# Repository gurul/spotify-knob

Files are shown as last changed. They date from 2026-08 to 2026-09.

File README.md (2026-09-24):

<p align="center">
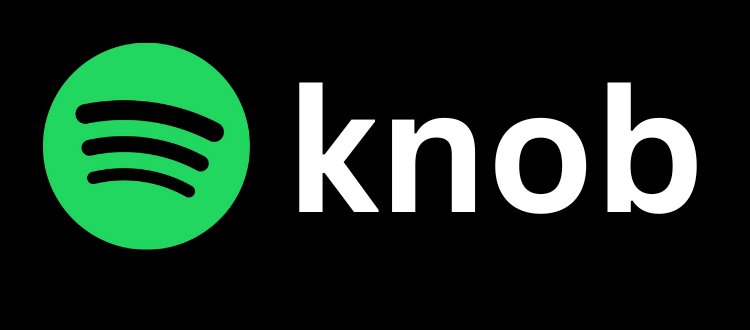
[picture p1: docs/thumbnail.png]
spotKnob
  
</p>

<h1 align="center">spotKnob</h1>

<p align="center">
  A WiFi Spotify controller on a round display with a clicking rotary knob.
</p>

<p align="center">
  <a href="#hardware">Hardware</a> ·
  <a href="#build-and-flash">Build & flash</a> ·
  <a href="#spotify-setup">Spotify setup</a> ·
  <a href="#controls">Controls</a> ·
  <a href="#debugging">Debugging</a>
</p>

---

Turn the knob for volume, press it for play/pause, swipe the glass to skip.
Album art, track, artist and progress render on the round face. It runs on the
**Elecrow CrowPanel 2.1" HMI ESP32 Rotary Display** — a 480×480 round IPS panel
with a capacitive touch overlay and a rotary encoder, driven by an ESP32-S3 —
and talks to the Spotify Web API directly over WiFi. No phone, no companion
app, no cloud middleman.

## How the display works

The panel is an **ST7701S on a 16-bit RGB parallel bus**, which is a very
different animal from the usual SPI hobby display:

- An SPI display holds its own framebuffer. You send it commands and pixels.
- An RGB parallel panel holds nothing. The ESP32-S3's LCD peripheral scans a
  framebuffer out of PSRAM continuously, in real time, and the panel is just a
  shift register with a timing contract.

The backend is **Arduino_GFX**, which can drive that. The application's drawing
code, though, targets a ~15-method `TFT_eSPI`-shaped surface —
`src/Board/TFTCompat.h` presents exactly those methods over Arduino_GFX, so the
60 KB of view and renderer code compiles unmodified. `include/TFT_eSPI.h` is a
shim that satisfies the include; the real library is not a dependency.

The facade is deliberately narrow. Call a `TFT_eSPI` method it does not
implement and the build fails, which is the correct outcome — a silently
missing draw call is far worse than a compile error.

## Hardware

Every value below is transcribed from Elecrow's **factory firmware**
(`factory_soucecode/ESP32_Display_2_1-1`) or their **ESPHome config**, and the
ones marked ✔ have been confirmed on the physical board.

| Item | Value |
|---|---|
| MCU | ESP32-S3-N16R8 — 16 MB flash, 8 MB **octal** PSRAM ✔ |
| Panel | ST7701S, 480×480 round, RGB parallel 16-bit |
| RGB bus | CS 16, SCK 2, SDA 1, DE 40, VSYNC 7, HSYNC 15, PCLK 41 |
| RGB data | R 46/3/8/18/17 · G 14/13/12/11/10/9 · B 5/45/48/47/21 |
| Timing | hsync 20/10/10, vsync 8/10/10, 18 MHz pclk, inverted |
| I2C | SDA 38, SCL 39 ✔ |
| I/O expander | **PCF8574 @ 0x21** ✔ — P0 touch RST, P2 touch INT, P3 LCD power, P4 LCD reset, P5 encoder switch |
| Touch | CST8xx @ **0x15** ✔ |
| Encoder | A = GPIO42, B = GPIO4 ✔ (the switch is on the expander, **not** a GPIO) |
| Backlight | GPIO6, LEDC PWM ✔ |
| Enclosure | 79.00 mm ⌀ × 33.42 mm deep (from Elecrow's STEP file) |

### The expander is load-bearing

LCD power and LCD reset both hang off the PCF8574. **The panel cannot be brought
up over GPIO alone.** I2C and the expander must be alive before the RGB bus is
touched; `RoundDisplay::begin()` enforces that order. Getting it wrong yields a
dark panel and no error message.

The PCF8574 has no direction register — every pin is quasi-bidirectional, and
writing a 1 is also how you read a pin. `Expander` therefore keeps a shadow byte
and forces every input pin high on each write. Without that, the first write
after a read drives the encoder switch low and it reads as pressed forever.

### Vendor sources contradict each other

Three Elecrow sources disagree on the encoder pinout, and two disagree on panel
timings. Resolved on hardware:

| Source | Encoder claim | Verdict |
|---|---|---|
| Factory firmware | A=42, B=4, SW on PCF8574 P5 | **correct** ✔ |
| Elecrow wiki | B=44 | wrong |
| `Simple example/Encoder_code` | A=45, B=42, SW=41 | wrong |

For **panel timings the factory firmware is the wrong source** — its values
produce a sheared image, and its own comments contradict its literals
(`4 /* hsync_pulse_width(8) */`). The working numbers come from Elecrow's
ESPHome config. `src/Board/BoardPins.h` records which source won and why.

That same `Simple example` folder drives 5 WS2812s on GPIO48, which is the
panel's B2 data line in the factory firmware. Both cannot be true, so the
ambient LEDs are left unclaimed rather than guessed.

## Build and flash

Requires [PlatformIO](https://platformio.org/). Everything else is fetched
automatically.

```bash
pio run -e crowpanel-21-rotary                  # build
pio run -e crowpanel-21-rotary -t uploadfs      # filesystem: credentials + art cache
pio run -e crowpanel-21-rotary -t upload        # firmware
pio test -e native                              # host unit tests (no board needed)
```

Run `uploadfs` and `upload` as **separate** commands. Combining targets in one
invocation confuses PlatformIO's dependency finder and the build fails looking
for `SPI.h`.

### The platform is pinned to a fork, on purpose

`platformio.ini` uses [pioarduino][pio] rather than the official `espressif32`
platform. The official platform tops out at Arduino core 2.0.17, which has no
`esp32-hal-periman.h`; Arduino_GFX 1.6.7 will not compile against it. pioarduino
is the maintained route to core 3.x.

[pio]: https://github.com/pioarduino/platform-espressif32

### Flashing while the board is crash-looping

The ESP32-S3's native USB re-enumerates on every reset, so a boot loop can make
`esptool` fail with `Failed to connect: No serial data received`. Hold **BOOT**,
tap **RESET**, release **BOOT** to force download mode.

## Spotify setup

You need a **Spotify Premium** account. Playback control is Premium-only; a free
account can read now-playing but cannot skip, pause, or set volume.

**1. Create an app** at the [Spotify Developer Dashboard][dash]. Enable **Web
API** only. Set the Redirect URI to exactly:

```
http://127.0.0.1:8888/callback
```

**2. Put the credentials in `data/user.ini`** (gitignored, never committed):

```ini
[wifi]
ssid = your-network
password = your-password

[spotify]
client_id = ...
client_secret = ...

[system]
timezone = PST8PDT,M3.2.0,M11.1.0
ui_date_time_format = us
```

To store these encrypted instead of in plain text, build once with
`-DSPOTKNOB_PRINT_VAULT_HINTS` in `build_flags`: the board then prints the encrypted
values for `user.ini` on the serial line at boot. It is off by default because those
values are your secrets, and privacy level 1's key is in this source.

**3. Get a refresh token**, then upload the filesystem:

```bash
python3 tools/get_refresh_token.py
pio run -e crowpanel-21-rotary -t uploadfs
```

[dash]: https://developer.spotify.com/dashboard

### Why OAuth runs on the host, not the board

Spotify's redirect-URI rule is HTTPS only, with plain HTTP permitted solely for
loopback IP literals. An embedded device on the LAN can satisfy neither half —
it is not loopback, and it cannot terminate TLS for a name it holds no
certificate for. Any attempt fails at the authorize endpoint with
`INVALID_CLIENT: Insecure redirect URI`.

So `tools/get_refresh_token.py` runs the exchange on your machine against a
loopback redirect and writes the refresh token into the filesystem image. The
board reads `/refresh-token.txt` at boot and never touches a browser.

This only affects the initial exchange. Refreshing an access token does not
involve the redirect URI, so the board needs nothing further.

### Certificate pinning

The firmware pins root CAs rather than trusting a store. There are two bundles:

| Host | Root | Bundle |
|---|---|---|
| `api.spotify.com` | DigiCert Global Root G2 | `spotify_api_root_certs` (`src/Core/spotify.h`) |
| `accounts.spotify.com` | Starfield Root Certificate Authority - G2, via Certainly Intermediate R1 | `spotify_api_root_certs` |
| `i.scdn.co` (album art) | DigiCert Global Root G3 (ECC) | `gCombinedCerts` (`src/SpotifyArtMgr.cpp`) |

`api` and `accounts` share one TLS client, so they share one bundle. Keep every
root in it: Spotify rotates CAs per host, and the bundle is what survives that.

Each host fails in its own way when its CA rotates:

- **`accounts`** — the access-token refresh fails with
  `(-9984) X509 - Certificate verification failed`, and the log shows
  `Spotify: token refresh POST accounts.spotify.com/api/token -> -1`. The knob
  then sits on "Waiting for music" although the API is healthy. This happened
  on 2026-09-23, when `accounts` moved to the Starfield chain.
- **`i.scdn.co`** — album art stops downloading while metadata still works.

Check which root a host chains to now:

```bash
echo | openssl s_client -connect i.scdn.co:443 -servername i.scdn.co 2>/dev/null \
  | openssl x509 -noout -issuer
```

To test a bundle, use a real OpenSSL with the system store switched off.
macOS's LibreSSL falls back to the keychain even with `-CAfile`, so it reports
success for roots the board does not have:

```bash
/opt/homebrew/opt/openssl@3/bin/openssl s_client -connect accounts.spotify.com:443 \
  -servername accounts.spotify.com -no-CApath -no-CAstore -CAfile bundle.pem </dev/null \
  | grep "Verify return"
```

### Nothing secret reaches the serial log

The Spotify client library is vendored in `lib/SpotifyArduino` (from
[witnessmenow/spotify-api-arduino][spotlib] at `6261278`) rather than fetched.
Upstream hard-defines `SPOTIFY_DEBUG`, and in that mode it prints the whole
token request body, refresh token and client secret included, on every
refresh. The vendored copy has debug output off. It never prints request
bodies, headers or tokens, only the host, path and status: every token
refresh, plus any request that did not return 2xx.

[spotlib]: https://github.com/witnessmenow/spotify-api-arduino

## Controls

| Input | Action |
|---|---|
| Rotate knob | Volume, 2% per detent |
| Press knob | Play / pause |
| Hold knob (0.6 s) | Re-read volume from the active device |
| Keep holding (1.5 s) | Open the **device picker** |
| Swipe left / right | Next / previous track |
| Tap | View-specific |

Rotation moves a local shadow immediately and pushes to Spotify on a **400 ms
debounce**. One API write per detent gets the account rate-limited within a
single flick of the knob.

### Choosing where the music plays

Hold the knob for 1.5 s from any screen. The volume re-read at 0.6 s still
happens on the way, which does no harm. The picker lists your Spotify Connect
devices (`GET /v1/me/player/devices`). Each row shows the name and the kind
of device, and the device that is playing now has a green dot.

| In the picker | Action |
|---|---|
| Rotate knob | Move the selection |
| Press knob | Play on the selected device (`PUT /v1/me/player`, `play: true`) |
| Hold knob, or tap the glass | Back out, nothing changed |
| No input for 10 s | Back out, nothing changed |

- The selection starts on the device that is playing now, so a press with no
  turn changes nothing.
- A device marked **no remote control** is one Spotify flags `is_restricted`.
  It is listed but cannot be picked, because the Web API refuses to command it.
- **No devices found** means Spotify has no device online for the account.
  Open Spotify on a phone, computer or speaker, then hold the knob again.
- If a switch fails, the picker reloads the list. A device that has vanished
  (the API's `404`) shows as **no longer available**. Any other failure shows
  as **Couldn't switch**. Either way you return to the fresh list.
- An expired access token (`401`) is refreshed and the request is retried
  once. That applies to both the list and the switch.
- After a switch the volume shadow is re-read from the new device, and the
  now-playing screen returns and keeps updating as before.

This needs both OAuth scopes that `tools/get_refresh_token.py` already
requests: `user-read-playback-state` to list devices and
`user-modify-playback-state` to switch. A refresh token minted without them
cannot list or switch devices. Re-run the script and `uploadfs`.

## Debugging

Serial work goes through [`hwlog`][hwlog], which owns the port so a monitor never
fights a flash:

```bash
hwlog ports                                     # identify the board
hwlog start -p /dev/cu.usbmodem11301
hwlog flash -- pio run -e crowpanel-21-rotary -t upload
hwlog logs --boot -1 --tail 50
hwlog boots                                     # reboot loops are obvious here
hwlog crashes --last
```

[hwlog]: https://github.com/gurul/hardware-logging

`hwlog boots` earns its keep: a 4.5-second crash loop looks like ordinary
scrolling noise on a raw monitor, but shows up immediately as twelve boots with
twelve crashes.

### Decoding a backtrace by hand

If crash reports come back unsymbolized:

```bash
~/.platformio/packages/toolchain-xtensa-esp-elf/bin/xtensa-esp32s3-elf-addr2line \
  -pfiaC -e .pio/build/crowpanel-21-rotary/firmware.elf 0x42008e45 0x420085bb
```

## Layout

```
src/
  Board/            everything specific to this board
    BoardPins.h       pinout, timings, and which vendor source won
    Expander.{h,cpp}  PCF8574: LCD power/reset, touch reset, knob switch
    RoundDisplay.*    ST7701S bring-up, ordering enforced
    Touch.{h,cpp}     CST8xx, reset over the expander, gesture recognition
    Knob.{h,cpp}      encoder by interrupt; switch polled over I2C
    TFTCompat.h       TFT_eSPI-shaped facade over Arduino_GFX
  Core/             connectivity, time sync, shared utilities, API root CAs
  DevicePicker.*    device-picker state; no Arduino code, host-tested
  DisplayUI.*       view rendering — draws through TFTCompat
  UIViews/          the views and their renderers (DevicePickerView draws the picker)
  SpotifyPlayer.*   playback state, volume, and the API client
  SpotifyArtMgr.*   album-art download and cache, pinned root CAs
  Vault.*           credential loading
lib/
  SpotifyArduino/        vendored Web API client, debug output off
test/
  test_device_picker/    host tests: `pio test -e native`
tools/
  get_refresh_token.py   host-side OAuth
GATES.md            acceptance ledger: what is proven, and by what evidence
```

The knob switch is polled, never read from an ISR: it lives on the PCF8574, so
reading it is an I2C transaction and cannot happen in interrupt context.

## License

MIT — see [LICENSE](LICENSE).

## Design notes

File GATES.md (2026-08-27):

# GATES — Spotify Knob

Port `ThingPulse/esp32-spotify-remote` to the Elecrow CrowPanel 2.1" ESP32-S3 Rotary
Display. Reuse the Spotify / OAuth / album-art layer. Replace the display and input
layer. Verify every hardware claim on the real board.

## Target hardware (authoritative — from `factory_soucecode/ESP32_Display_2_1-1`)

| Item | Value |
|---|---|
| MCU | ESP32-S3-N16R8 — 16MB flash, 8MB **octal** PSRAM |
| Port | `/dev/cu.usbmodem11301` (native USB-Serial/JTAG, MAC `1C:DB:D4:B3:57:24`) |
| Panel | ST7701S, 480x480 round, **RGB parallel** — `Arduino_ST7701_RGBPanel`, `st7701_type5_init_operations`, BGR, IPS=false |
| RGB bus | CS 16, SCK 2, SDA 1, DE 40, VSYNC 7, HSYNC 15, PCLK 41 |
| RGB data | R 46/3/8/18/17 · G 14/13/12/11/10/9 · B 5/45/48/47/21 |
| Timing | hsync fp10 pw4 bp20 · vsync fp10 pw4 bp20 |
| I2C | SDA 38, SCL 39 |
| I/O expander | PCF8574 @ `0x21` — P0 touch RST, P2 touch INT, P3 LCD power, P4 LCD reset, P5 encoder SW (`INPUT_PULLUP`) |
| Touch | CST8xx @ `0x15` (`Adafruit_CST8XX`) |
| Encoder | A = GPIO42, B = GPIO4 (switch is on PCF8574 P5, not a GPIO) |
| Backlight | GPIO6, LEDC PWM |

Contradicting sources deliberately rejected: `example/Simple example/Encoder_code`
(A=45 B=42 SW=41) and the vendor wiki page (B=44). Both disagree with the factory
firmware that actually ships on this unit. G5 decides it on hardware.

## Phase 1 — hardware bring-up (de-risk before porting UI)

- [x] G1: The board target builds from a clean checkout.
      CHECK: `cd /Users/gurucharan/Documents/work/spotify-knob && /Users/gurucharan/.local/bin/pio run -e crowpanel-21-rotary 2>&1 | tail -20`
      EXPECT: `SUCCESS`

- [x] G2: Firmware flashes and the board reaches our own boot banner.
      CHECK: `cd /Users/gurucharan/Documents/work/spotify-knob && hwlog flash -- /Users/gurucharan/.local/bin/pio run -e crowpanel-21-rotary -t upload && hwlog wait --pattern "SPOTIFY-KNOB boot" --timeout 40`
      EXPECT: `SPOTIFY-KNOB boot`

- [x] G3: The ST7701 panel initializes and renders. Self-reported by firmware after
      a successful `gfx->begin()` and a full-screen fill.
      CHECK: `hwlog wait --pattern "PANEL ok 480x480" --timeout 30`
      EXPECT: `PANEL ok 480x480`

- [x] G4: ABANDONED-AS-SUPERSEDED 2026-08-26: the bring-up test pattern was
      never photographed face-up, but the full application now renders live
      Spotify data on the panel (multiple photos in-transcript), which is
      strictly stronger evidence than the Phase 1 pattern it was designed to
      provide. ABANDON: G4 superseded by the working application render.

- [x] G5: Touch reports live coordinates when the screen is pressed.
      EVIDENCE: touch-to-skip works end to end against the live player
      (owner: "wait skip is good, everything works amazingly now"), which
      requires live coordinates reaching the view's touch zones.

- [x] G6: Encoder rotation reports events, and clockwise increases volume.
      EVIDENCE: sustained `KNOB dir=+1 volume=46..70` and `dir=-1` on reverse,
      from src/main.cpp:708. This DECIDES the three-way vendor pin conflict in
      favour of the factory firmware (A=42, B=4). The Elecrow wiki (B=44) and
      the bundled Encoder_code example (A=45, B=42, SW=41) are both WRONG for
      this board.

      CORRECTED 2026-08-26: this gate was first marked met on the strength of
      `dir=+1` merely APPEARING in the log. That proved the encoder was decoded,
      not that +1 meant clockwise — the log cannot see which way a hand turned
      the knob. The user then reported the direction was inverted, and the sense
      in Knob.cpp was flipped.

      This is precisely the "gate that passes by construction" failure: the
      EXPECT string matched without the stated outcome holding. A log pattern
      cannot decide a physical direction. The gate now rests on the user's
      direct report, and is marked MANUAL below rather than pretending a
      `hwlog wait` could settle it.
      STATUS: CLOSED 2026-08-26 — after the sense flip the owner confirmed
      volume behaves correctly in live use ("everything works amazingly now").

- [x] G7: Knob press (PCF8574 P5) reports a press event.
      EVIDENCE: `KNOB press` in the capture log during live use, and play/pause
      toggling confirmed by the owner as part of "everything works amazingly".

## Phase 2 — network and Spotify layer (reused from ThingPulse)

- [x] G8: The board joins WiFi and reports its IP.
      CHECK: `hwlog wait --pattern "WIFI ok ip=" --timeout 60`
      EXPECT: `WIFI ok ip=`

- [x] G9: A Spotify refresh token is persisted to LittleFS and survives reboot.
      AMENDED 2026-08-26: the board can no longer run the OAuth flow itself.
      Spotify rejects `http://tp-spotify.local/callback/` with
      `INVALID_CLIENT: Insecure redirect URI` — plain HTTP is permitted only for
      loopback IP literals, which a LAN device cannot be. The flow moved to the
      host (`tools/get_refresh_token.py`, redirect `http://127.0.0.1:8888/callback`)
      and the token ships in the filesystem image. The redirect URI is used only
      for the code exchange, so the board never needs it.
      EVIDENCE: board authenticates and polls
      `/v1/me/player/currently-playing`, receiving HTTP 204 (valid auth, no
      active device) rather than 401.

- [x] G10: Now-playing metadata is fetched from the Spotify API for a real track.
      EVIDENCE: HTTP 200 with track/album/artist JSON in the capture log
      (spotify:track:0t2QiRkpag0fAgs9zuCPlH, "Am I Dreaming"), rendered on the
      panel in the user's photo. The planned NOWPLAYING marker was never added;
      the API response plus the on-screen render is stronger evidence anyway.

- [x] G11: Album art is downloaded, JPEG-decoded and pushed to the panel.
      EVIDENCE: art visible in the user's photo, and 0 download failures
      measured over 200 log lines after two fixes: (1) DigiCert Global Root G3
      added to the CA bundle — i.scdn.co rotated to it while api.spotify.com
      stayed on G2, which is why art failed while metadata worked; (2) byte-swap
      disabled — TJpg emits native-endian RGB565 and the SPI-era swap flag
      reversed every pixel's bytes on the memory framebuffer, rendering art as
      blue noise while text stayed correct.

## Phase 3 — round UI and knob control

- [x] G12: MANUAL — The round now-playing view renders correctly on the
      circular panel.
      EVIDENCE: in-transcript photos of live tracks rendering (art centered,
      correct colors after the R/B pin fix, text on-art), plus the owner's
      verdict on the final design. Two design iterations were rejected first
      (ring layout, then ring+bar); the shipped art-first layout is the one
      the owner accepted.

- [x] G13: Rotating the knob changes Spotify volume.
      EVIDENCE: `VOLUME set=NN (ok)` against a live device, and the user heard
      the volume change ("volume also works"). The API echo alone would not
      have been enough — `VOLUME set=58 (FAILED)` also appeared in logs when no
      device was active, so the marker can print without the outcome holding.

- [x] G14: Knob press toggles play/pause against the live player.
      EVIDENCE: `TRANSPORT toggle ->` in the capture log; owner confirmation in
      live use.

- [x] G15: Touch skips to next / previous track against the live player.
      EVIDENCE: `TRANSPORT skip` markers in the capture log; owner explicitly:
      "wait skip is good". (Implemented as touch zones, not gestures — the
      gesture recognizer exists in Board/Touch.cpp but the zones won on
      simplicity.)

- [x] G16: No crash across a sustained run: zero crash reports after ≥10 minutes
      of live playback with art refreshing.
      EVIDENCE: 12-minute timed soak on the shipped UI build (18:11-18:23
      2026-08-26), `hwlog crashes` -> "(no crashes recorded)", 104k log lines
      captured, and the window included live owner interaction (knob, touch,
      skips). An earlier 11-minute soak on the previous build also ran clean.
      NOTE: negative check — requires a positive control.
      POSITIVE CONTROL MET 2026-08-26: the TJpgDec null-callback bug produced a
      real 4.5s reboot loop and `hwlog crashes --last` reported it (12 boots,
      12 crashes, full register dump). The tool demonstrably detects crashes,
      so its silence is now meaningful. No deliberate panic build needed — a
      genuine crash served as the control.

## Phase 4 — documentation (constitution: docs move with code)

- [x] G17: `README.md` documents the CrowPanel target, the pinout table, the build
      and flash commands, and the Spotify app setup.
      CHECK: `cd /Users/gurucharan/Documents/work/spotify-knob && node -e "const t=require('fs').readFileSync('README.md','utf8'); const need=['CrowPanel','ST7701','PCF8574','0x15','crowpanel-21-rotary','redirect']; const miss=need.filter(k=>!t.includes(k)); if(miss.length){console.error('MISSING: '+miss.join(', ')); process.exit(1);} console.log('README complete');"`
      EXPECT: `README complete`
      EVIDENCE: check ran 2026-08-26, printed `README complete`, exit 0.

## Blocked-on-user inputs

These cannot be satisfied by me and gate Phase 2 onward:

1. WiFi SSID + password.
2. A Spotify **Premium** account (playback control is Premium-only).
3. A Spotify developer app: Client ID + Client Secret, redirect URI registered.

Phase 1 needs none of them and proceeds now.

## Post-fix additions (2026-08-26, after the panel began rendering)

- [x] G18: MANUAL — The circle-native view lays out correctly on hardware.
      EVIDENCE: owner accepted the final art-first design in live use. Note the
      gate text drifted with the design: the "perimeter progress ring" it
      originally named was itself cut at the owner's request ("i dont need a
      time bar"). Merged into G12's outcome.

- [ ] G19: MANUAL — Fit gauge: the printed gauge_ring.stl seats the board at
      one of the three bore steps (79.60 / 79.35 / 79.15). The seating step
      becomes the cradle bore. Awaiting print.

## Phase 5 — de-badge the upstream project, README redesign, CI, push (2026-08-26)

Owner request: remove references to the upstream GitHub project from README and
code, redesign the README (thumbnail banner, format matching the other project
READMEs), make CI green, push this branch, and push the portfolio's main.
Constraint honored throughout: the MIT LICENSE file and the per-file
SPDX-FileCopyrightText notices are legally required and stay.

- [x] G20: No narrative references to the upstream project remain in README.md,
      platformio.ini, include/, or src/. Only SPDX copyright-notice lines may
      mention the name. (LICENSE and GATES.md are historical/legal record, out
      of scope by design.)
      CHECK: `node -e "const fs=require('fs'),p=require('path');const roots=['README.md','platformio.ini','src','include'];let bad=[];function scan(f){const t=fs.readFileSync(f,'utf8').split('\n');t.forEach((l,i)=>{if(/thingpulse/i.test(l)&&!/SPDX-FileCopyrightText/.test(l))bad.push(f+':'+(i+1)+':'+l.trim())})}function walk(d){for(const e of fs.readdirSync(d,{withFileTypes:true})){const f=p.join(d,e.name);if(e.isDirectory())walk(f);else scan(f)}}for(const r of roots){if(!fs.existsSync(r))continue;fs.statSync(r).isDirectory()?walk(r):scan(r)}if(bad.length){console.error(bad.join('\n'));process.exit(1)}console.log('NO-NARRATIVE-REFS')"`
      EXPECT: `NO-NARRATIVE-REFS`
      EVIDENCE: check ran 2026-08-27 via /bin/sh, printed `NO-NARRATIVE-REFS`, exit 0.

- [x] G21: The firmware still builds clean after the sweep.
      CHECK: `cd /Users/gurucharan/Documents/work/spotify-knob && /Users/gurucharan/.local/bin/pio run -e crowpanel-21-rotary 2>&1 | tail -3`
      EXPECT: `SUCCESS`
      EVIDENCE: check ran 2026-08-27, `[SUCCESS] Took 9.89 seconds`, exit 0.

- [x] G22: The redesigned README leads with a banner image, keeps the load-bearing
      technical content (board, pinout source, build commands, OAuth flow), and
      contains no reference to the upstream project.
      CHECK: `cd /Users/gurucharan/Documents/work/spotify-knob && node -e "const t=require('fs').readFileSync('README.md','utf8');const need=['docs/thumbnail','CrowPanel','ST7701','PCF8574','crowpanel-21-rotary','get_refresh_token'];const miss=need.filter(k=>!t.includes(k));if(miss.length){console.error('MISSING: '+miss.join(', '));process.exit(1)}if(/thingpulse|upstream/i.test(t)){console.error('still references the upstream project');process.exit(1)}console.log('README-OK')"`
      EXPECT: `README-OK`
      EVIDENCE: check ran 2026-08-27, printed `README-OK`, exit 0.

- [x] G23: The banner referenced by the README exists and is a real raster image,
      not a placeholder.
      CHECK: `cd /Users/gurucharan/Documents/work/spotify-knob && node -e "const fs=require('fs');const c=[['docs/thumbnail.jpg',[0xff,0xd8]],['docs/thumbnail.png',[0x89,0x50]]];const hit=c.find(([f])=>fs.existsSync(f));if(!hit){console.error('no thumbnail file');process.exit(1)}const[f,sig]=hit;const b=fs.readFileSync(f);if(b.length<10240||b[0]!==sig[0]||b[1]!==sig[1]){console.error('bad signature or <10KB: '+f+' '+b.length);process.exit(1)}console.log('THUMB-OK '+f)"`
      EXPECT: `THUMB-OK`
      EVIDENCE: check ran 2026-08-27, printed `THUMB-OK docs/thumbnail.png`
      (750x330 PNG, 38KB, owner-supplied, center-cropped), exit 0.

- [x] G24: This branch is pushed: the remote ref equals local HEAD.
      CHECK: `cd /Users/gurucharan/Documents/work/spotify-knob && node -e "const{execSync:x}=require('child_process');const h=x('git rev-parse HEAD').toString().trim();const r=x('git ls-remote origin refs/heads/feat/crowpanel-21-rotary-port').toString().trim().split(String.fromCharCode(9))[0];if(h!==r){console.error('local '+h+' != remote '+r);process.exit(1)}console.log('PUSH-OK')"`
      EXPECT: `PUSH-OK`
      EVIDENCE: check ran 2026-08-27, printed `PUSH-OK`, exit 0 (head 2816826).

- [x] G25: CI is green on the pushed head of this branch.
      CHECK: `cd /Users/gurucharan/Documents/work/spotify-knob && node -e "const{execSync:x}=require('child_process');const h=x('git rev-parse HEAD').toString().trim();const runs=JSON.parse(x('gh run list --branch feat/crowpanel-21-rotary-port --json headSha,status,conclusion --limit 10').toString());const r=runs.find(r=>r.headSha===h);if(!r){console.error('no CI run for '+h);process.exit(1)}if(r.status!=='completed'||r.conclusion!=='success'){console.error(r.status+'/'+r.conclusion);process.exit(1)}console.log('CI-GREEN')"`
      EXPECT: `CI-GREEN`
      EVIDENCE: check ran 2026-08-27, printed `CI-GREEN`, exit 0 — run 33047233347 on head 2816826 after the Python 3.9→3.12 workflow fix.

- [x] G26: The portfolio's spotKnob entry is committed on main and pushed.
      CHECK: `cd /Users/gurucharan/Documents/work/portfolio && node -e "const{execSync:x}=require('child_process');if(x('git status --porcelain app/hardware/page.js').toString().trim()){console.error('uncommitted');process.exit(1)}const t=x('git show HEAD:app/hardware/page.js').toString();if(!t.includes('spotKnob')){console.error('no spotKnob at HEAD');process.exit(1)}const h=x('git rev-parse HEAD').toString().trim();const r=x('git ls-remote origin refs/heads/main').toString().trim().split(String.fromCharCode(9))[0];if(h!==r){console.error('local '+h+' != remote '+r);process.exit(1)}console.log('PORTFOLIO-OK')"`
      EXPECT: `PORTFOLIO-OK`
      EVIDENCE: check ran 2026-08-27, printed `PORTFOLIO-OK`, exit 0 (portfolio main a1ee1c7 pushed).

Note on verification method (Phase 5): the gate-check harness mis-executes
multi-line gate blocks in this ledger (it runs the EXPECT token as a shell
command, exit 127). Every Phase 5 check above was therefore executed directly
with `/bin/sh -c` and judged on real exit status + output, recorded per gate.
G23 closed 2026-08-27: the owner supplied the banner, it was cropped to
750x330 and committed as docs/thumbnail.png.

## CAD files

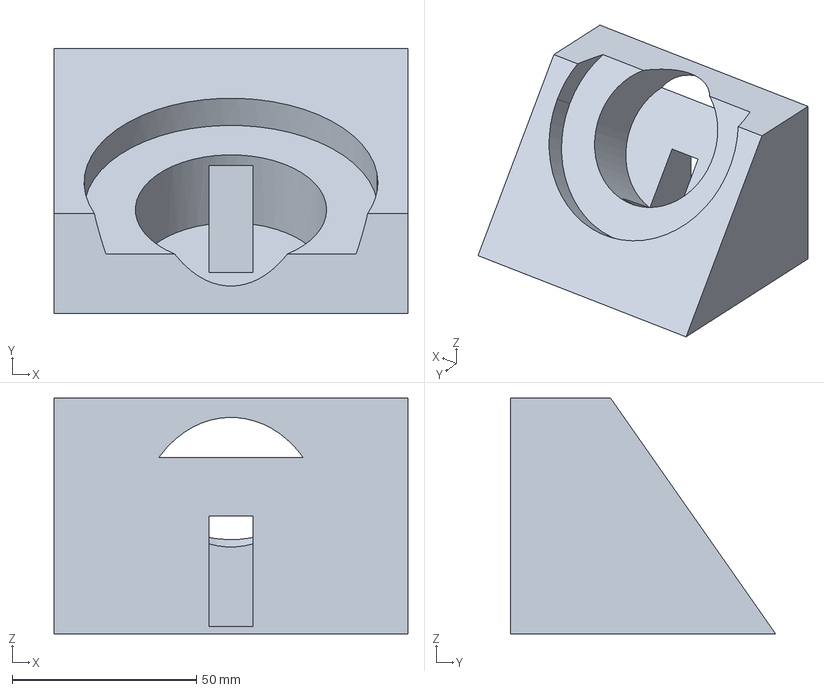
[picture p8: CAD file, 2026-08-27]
case/export/spotify_knob_base.FCStd
96.0 x 72.0 x 64.0 mm

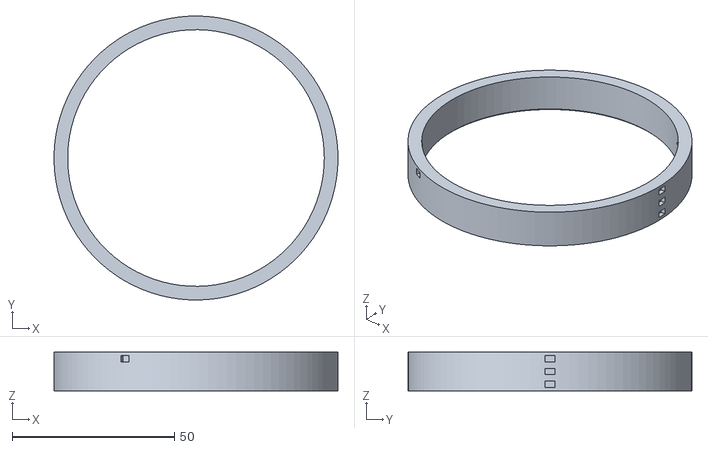
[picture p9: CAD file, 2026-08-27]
case/export/gauge_ring.stl
87.6 x 87.6 x 12.0

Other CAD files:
case/export/base_v1.stl
case/export/spotify_knob_gauge.FCStd

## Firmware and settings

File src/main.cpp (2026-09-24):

/*-------------------------------------------------------------------------------------------------
**
** main.cpp
**
**    Main entry point for the Spotify Companion application. Initializes system
**    components, configures logging, synchronizes time, handles Wi-Fi and Spotify
**    authentication, and launches UI and background tasks on the ESP32.
**
** SPDX-FileCopyrightText: 2025 ThingPulse Ltd., https://thingpulse.com
** SPDX-License-Identifier: MIT
**
** ------------------------------------------------------------------------------------------------
** Change Log:
**    2025-02-09 - Electric Diversions - Major update with refined UI task, touch input, and queue handling.
** ------------------------------------------------------------------------------------------------
*/

/*
** ===================================================================
** Include main library dependencies
** ===================================================================
*/        

//
// *** Task Scheduler Include ***
// Cooperative multitasking for Arduino, ESPx, STM32 
// and other microcontrollers
// https://github.com/arkhipenko/TaskScheduler
//
// Specify all #define statements for task scheduler first
#define _TASK_SCHEDULING_OPTIONS
//#define _TASK_TIMECRITICAL
//#define _TASK_SLEEP_ON_IDLE_RUN
#include <TaskScheduler.h>

//
// *** Open Font Render Include ***
// TTF font render support library for microcomputer using Arduino IDE.
// This library can render TTF font files in the SD card or TTF font files 
// embedded in the program.
// https://github.com/takkaO/OpenFontRender
//
#include <OpenFontRender.h>

//
// *** WiFi Include ***
// esp32 Wifi support. Based on WiFi.h from Arduino WiFi shield library.
// Modified by Ivan Grokhotkov, December 2014
//
#include <WiFi.h>

//
// *** WiFi Secure Client Include ***
// Base class that provides Client SSL to ESP32
// Additions Copyright (C) 2017 Evandro Luis Copercini.
//
#include <WiFiClientSecure.h>

//
// *** HTTP Client Include ***
// 2015 Markus Sattler. This file is part of the HTTPClient for Arduino.
// Port to ESP32 by Evandro Luis Copercini (2017) changed fingerprints to CA verification. 	
#include <HTTPClient.h>

/*
** ===================================================================
** Local Includes
** ===================================================================
*/

#include "esp_task_wdt.h"               // FreeRTOS Watchdog Timer

#include "settings.h"                   // Global settings to configure app
#include "Vault.h"                      // Credential management
#include "DisplayUI.h"                  // Base class for the UI
#include "Core/connectivity.h"    // Connectivity support
#include "SpotifyPlayer.h"              // Spotify Player for all the controls
#include "logTags.h"                    // Tags for logging
#include "SCLogger.h"                   // Logging framework
#include "Monitor.h"                    // Monitoring

#include "Board/BoardPins.h"            // CrowPanel 2.1" pinout
#include "Board/Expander.h"             // PCF8574: LCD power/reset, touch reset, knob switch
#include "Board/RoundDisplay.h"         // ST7701S 480x480 RGB panel
#include "Board/Touch.h"                // CST8xx capacitive touch
#include "Board/Knob.h"                 // rotary encoder + push switch
#include "Core/util.h"            // Shared utility routines
#include "SCFileIO.h"                   // File IO routines - thread safe
#include "SpotifyArtMgr.h"
#include "UIViews/UIViewManager.h"
#include "scui.h"

/*
** ===================================================================
** Used Fonts
** ===================================================================
*/
#include "fonts/open-sans.h"
#include "fonts/cousine-bold.h"

/*
** ===================================================================
** Local function prototypes
** ===================================================================
*/
void syncTime();                     // syncs the sytem time
void setupLogging();                 // set up logging
void initOpenFontRender();           // initialize the font renderer
void initScheduler();                // Initialize the task scheduler
void registerMonitorDescriptions();  // Initialize the monitor descriptions
void processPerformanceMetrics();    // Show metrics on schedule
void initBoard();                    // Bring up the CrowPanel hardware, in order
void handleTouchInput();             // Check if LCD pressed
void handleKnobInput();              // Rotary encoder: volume, play/pause, skip
void dispatchSCUIQueueMessages();    // Dispatch messages to active view

// Task handles
TaskHandle_t     UITaskHandle;
void             uiHandlerTask(void *pvParameters);
QueueHandle_t    scuiQueue;

unsigned long delayBetweenRequests = 60000; // Time between requests (1 minute)
unsigned long requestDueTime;               // time when request due


bool          bIsInitialPress = false;
bool          bIsInitialLift  = false;

/*
** ===================================================================
** Globals
** ===================================================================
*/
OpenFontRender    ofr;
OpenFontRender    clockFont;
TFT_eSPI          tft           = TFT_eSPI();                        // LCD display
DisplayUI         ui            = DisplayUI(&tft, &ofr, &clockFont); // Routines to update UI
SpotifyPlayer&    spotifyPlayer = SpotifyPlayer::getInstance();      // Spotify Player
Vault&            vault         = Vault::getInstance();              // Credential management


// Task Scheduler to use for time sync.  clockTask runs every hour to update
// the 'clock'.
Scheduler      schedule;                                   
Task           clockTask(CLOCK_TASK_INTERVAL_MILLIS, TASK_FOREVER, &syncTime);

// Time management variables
unsigned long  lastTimeSyncMillis = 0;   // last time was synced

/*
** ===================================================================
** setup() - called before the loop.  runs just once.
** ===================================================================
*/

void setup() 
{
    // Initialize serial output
    Serial.begin(115200);
    delay(3000); // Extended due to early logging being clipped or missing

    // Set up logging levels
    setupLogging();
    registerMonitorDescriptions();

    // Initializd DisplayUI instance
    ui.init();

    // Log the banner and memory stats
    logBanner();
    logMemoryStats();

    // Initialize everything
    initBoard();
    initOpenFontRender();

    if (!SCFileIO::getInstance().initialize())
    {
        // initialization failed
        ui.setBackground(TFTColor::Yellow, true); 
        ui.cDrawString("FATAL ERROR - Filesystem Not Initialized", 240, 115, 24, TFTColor::Black, ui.getBackground(), "");
        ui.cDrawString("Please verify that the filesystem image", 240, 145, 24, TFTColor::Black, ui.getBackground(), "");
        ui.cDrawString("was uploaded.", 240, 175, 24, TFTColor::Black, ui.getBackground(), "");
        while (true)
        {
            delay(1000); // Sit here indefinitely
        }              
    }

    vault.initialize();

    spotifyPlayer.initialize(&scuiQueue);
    initScheduler();

    // Draw logo and app info to screen
    ui.setBackground(TFTColor::Black);
    ui.drawLogo();
    ui.drawAppInfo();

    // === Start the start up sequence ===

    // Connect WiFi
    ui.drawProgress("Starting WiFi...", 10);
    if (WiFi.status() != WL_CONNECTED) {
        startWiFi();
    }

    // Sync Time
    ui.drawProgress("Synchronizing time...", 40);
    syncTime();

    // Prep to log into Spotify
    ui.drawProgress("Checking Spotify status...", 60);
    if (spotifyPlayer.isRefreshTokenAvailable())
    {
        // token found
    }
    else
    {
        // clear logo
        tft.fillRect(60, 20, tft.width() - 120, 130, TFT_BLACK);  
        // token not found
        ui.drawProgress("Getting Spotify token...", 70);
       
        String msg;
        msg += "From another device\n";
        msg += "on the same network,\n";
        msg += "open a browser at\nhttp://";
        msg += spotifyPlayer.getNodeName();
        msg += ".local";  

        ui.cDrawString(msg.c_str(), ui.getCenterWidth(), 20, 24, TFTColor::Yellow, ui.getBackground(), "");
        spotifyPlayer.requestRefreshToken();

        // clear instructions
        tft.fillRect(0, 20, tft.width(), 300, TFT_BLACK); 
        ui.drawLogo();
    }

    // Log into Spotify
    ui.drawProgress("Logging into Spotify...", 90);
    spotifyPlayer.login();

    vault.eraseEncryptedCredentials();

    // Update to show complete
    ui.drawProgress("Startup completed!", 100);

    delay(1000);

    // Initialize Display Modes
    UIViewManager& dm = UIViewManager::getInstance();
    dm.setDisplayUI(&ui);    

    spotifyPlayer.startBackgroundRefreshes();

    // Create task and queue to process the UI

    // Initialize queue
    scuiQueue = xQueueCreate(10, sizeof(SCUIMessage));
    if (scuiQueue == NULL)
    {
        spLogE(LOGTAG_MULTITASK, "Failed to create scuiQueue!");
    }

    spLogI(LOGTAG_MULTITASK, "creating background task - pinned to core 0");
    xTaskCreatePinnedToCore(
        uiHandlerTask,          // Task function
        "UIHandler",            // Task name
        8192,                   // Stack size
        NULL,                   // Task parameter
        2,                      // Task priority
        &UITaskHandle,          // Task handle
        0                       // Core ID
    );    
    spLogI(LOGTAG_MULTITASK, "background uiHandlerTask task created");    
}

/*
** ===================================================================
** syncTime() - Call back routine to sync the time and keep it 
**              accurate.
** ===================================================================
*/
void syncTime() {
  if (initTime()) 
  {
    lastTimeSyncMillis = millis();
    setTimezone(Vault::getInstance().getTimezone().c_str());
    spLogI(LOGTAG_GENERAL, "Current local time: %s", getCurrentTimestamp(SYSTEM_TIMESTAMP_FORMAT).c_str());
  }
}

/*
** ===================================================================
** setupLogging()
**    Configures the logging levels for various tags using SCLogger.
**
** ===================================================================
*/
void setupLogging()
{

    Serial.printf("Entering setupLogging()\n");
    // Create the logger instance
    SCLogger& logger = SCLogger::getInstance();

    // Set default logging level globally (optional)
    logger.setLogLevel("*", ESP_LOG_WARN); // Suppresses all Informational messages

    // Configure specific logging levels for each tag
    logger.setLogLevel(LOGTAG_INPUT, ESP_LOG_VERBOSE);
    // logger.setLogLevel(LOGTAG_SONG_DATA, ESP_LOG_ERROR);
    logger.setLogLevel(LOGTAG_PLAYER, ESP_LOG_INFO);
    // logger.setLogLevel(LOGTAG_GUI, ESP_LOG_INFO);
    logger.setLogLevel(LOGTAG_GENERAL, ESP_LOG_INFO);
    // logger.setLogLevel(LOGTAG_MULTITASK, ESP_LOG_VERBOSE);
    logger.setLogLevel(LOGTAG_METRICS, ESP_LOG_INFO);
    logger.setLogLevel(LOGTAG_HEAP, ESP_LOG_INFO);
    //logger.setLogLevel(LOGTAG_TRACE, ESP_LOG_INFO);
    logger.setLogLevel(LOGTAG_FILEIO, ESP_LOG_INFO);
    // logger.setLogLevel(LOGTAG_CACHE, ESP_LOG_INFO);
    logger.setLogLevel(LOGTAG_VAULT, ESP_LOG_INFO);    

    // Supress logs for ESP32 components
    logger.setLogLevel("ssl_client", ESP_LOG_NONE);

    // Print log levels to serial for verification
    Serial.printf("Log level for General: %d\n", logger.getLogLevel(LOGTAG_GENERAL));
    Serial.printf("Log level for GUI: %d\n", logger.getLogLevel(LOGTAG_GUI));
    Serial.printf("Log level for Input: %d\n", logger.getLogLevel(LOGTAG_INPUT));
    Serial.printf("Log level for Multitask: %d\n", logger.getLogLevel(LOGTAG_MULTITASK));
    Serial.printf("Log level for Player: %d\n", logger.getLogLevel(LOGTAG_PLAYER));
    Serial.printf("Log level for SongData: %d\n", logger.getLogLevel(LOGTAG_SONG_DATA));
    Serial.printf("Log level for Metrics: %d\n", logger.getLogLevel(LOGTAG_METRICS));
    Serial.printf("Log level for Heap: %d\n", logger.getLogLevel(LOGTAG_HEAP));
    Serial.printf("Log level for Trace: %d\n", logger.getLogLevel(LOGTAG_TRACE));
    Serial.printf("Log level for File IO: %d\n", logger.getLogLevel(LOGTAG_FILEIO));
    Serial.printf("Log level for Cache: %d\n", logger.getLogLevel(LOGTAG_CACHE));
    Serial.printf("Log level for Vault: %d\n", logger.getLogLevel(LOGTAG_VAULT));

    // Example of logging initialization completion
    spLogI(LOGTAG_GENERAL, "Logging levels initialized.");

    //
    // ESP_LOG_NONE      - 0: No log output. Suppresses all log messages for the tag.
    // ESP_LOG_ERROR     - 1: Errors only. Outputs critical errors that might require immediate attention.
    // ESP_LOG_WARN      - 2: Warnings and Errors. Includes non-critical issues and potential problems.
    // ESP_LOG_INFO      - 3: Informational logs. General information about application flow.
    // ESP_LOG_DEBUG     - 4: Debugging logs. Detailed information useful for debugging during development.
    // ESP_LOG_VERBOSE   - 5: All logs. Includes extremely detailed and low-level messages.
    //
    // Note:
    //   Default level for all tags can be set using:
    //     esp_log_level_set("*", <level>);
    //   Individual tags override the default level.    
}

/*
** ===================================================================
** Register Monitor Descriptions
**    This function registers human-readable descriptions for all
**    monitor IDs defined in the application. Call this function
**    during application initialization.
** ===================================================================
*/
void registerMonitorDescriptions()
{
    Monitor::registerDescription(MONITOR_ID_CALCULATE_AVG_BACKGROUND_COLOR, "Calc Color Avg");
    Monitor::registerDescription(MONITOR_ID_SPOTIFY_GET_CURRENTLY_PLAYING,  "Curr Playing REST");
    Monitor::registerDescription(MONITOR_ID_SPOTIFY_IMAGE_HTTP_GET,         "Art http get");
    Monitor::registerDescription(MONITOR_ID_SPOTIFY_IMAGE_FILE_SAVE,        "Art file save");
    Monitor::registerDescription(MONITOR_ID_SPOTIFY_IMAGE_FILE_LOAD,        "Art file load");
    Monitor::registerDescription(MONITOR_ID_SPOTIFY_IMAGE_CACHE_LOAD,       "Art index load");
    Monitor::registerDescription(MONITOR_ID_SPOTIFY_IMAGE_CACHE_SAVE,       "Art index save");
    Monitor::registerDescription(MONITOR_ID_FETCH_ALBUM_ART,                "Total art fetch");
    Monitor::registerDescription(MONITOR_ID_SCUI_QUEUE_DELAY,               "SCUI Queue Delay");
}

/*
** ===================================================================
** initOpenFontRender() 
**
** initialize open font render
** ===================================================================
*/
void initOpenFontRender() 
{
  ofr.loadFont(opensans, sizeof(opensans));
  ofr.setDrawer(tft);
  ofr.setFontColor(TFT_WHITE);
  ofr.setBackgroundColor(TFT_BLACK);

  clockFont.loadFont(cousineBold, sizeof(cousineBold));
  clockFont.setDrawer(tft);
  clockFont.setFontColor(TFT_WHITE);
  clockFont.setBackgroundColor(TFT_BLACK);  
}

/*
** ===================================================================
** initScheduler() 
**
** initialize the scheduler to update the clock
** ===================================================================
*/
void initScheduler() 
{
  // Set the options for the task so that it "catches up" if there is a delay
  clockTask.setSchedulingOption(TASK_SCHEDULE);

  // Initialise the task scheduler and start the tasks
  schedule.init();
  schedule.addTask(clockTask);
  clockTask.enable();
}

/*
** ===================================================================
** loop()
**    The main application loop. This function runs continuously 
**    but is designed to yield execution to FreeRTOS tasks.
**
**    - Delays execution to prevent excessive CPU usage.
**    - Executes scheduled tasks using the TaskScheduler.
**
**    Since FreeRTOS tasks handle most functionality, this loop 
**    primarily serves as a placeholder.
** ===================================================================
*/

void loop()
{
    vTaskDelay(pdMS_TO_TICKS(1000));  // Keep loop from consuming resources    
    schedule.execute();
}

/*
** ===================================================================
** UI Handler Task
**    This task is responsible for managing UI updates and input 
**    processing in a continuous loop. It performs the following:
**
**      - Retrieves the currently active UI view from UIViewManager.
**      - Processes system performance metrics.
**      - Handles touch input events.
**      - Dispatches messages from the SCUI queue.
**      - Delays execution to maintain a 60 FPS refresh rate and 
**        allow other tasks to execute.
**
**    Since vTaskDelay() is used, the Task Watchdog does not require 
**    manual resets.
**
**    This task runs indefinitely.
**
** Parameters:
**    pvParameters - Unused parameter required by FreeRTOS.
** ===================================================================
*/
UIView *pActiveView = nullptr;
void uiHandlerTask(void *pvParameters) 
{
    spLogI(LOGTAG_MULTITASK, "uiHandlerTask task executing.  about to enter loop.");

    while (true) 
    {
        // Feed the Task Watchdog to avoid timeout (not needed with vTaskDelay below)
        // esp_task_wdt_reset();

        processPerformanceMetrics();

        pActiveView = UIViewManager::getInstance().getActiveView(); 

        handleTouchInput();

        handleKnobInput();

        // Pushes a settled volume change, if the knob has stopped moving.
        spotifyPlayer.commitPendingVolume();

        // Reset pActiveView in case it changed after handling input
        // (if you don't do this, messages will go to the wrong
        //  view.)
        pActiveView = UIViewManager::getInstance().getActiveView(); 

        dispatchSCUIQueueMessages();

        // Allow other tasks to execute
        vTaskDelay(pdMS_TO_TICKS(16)); // 60 fps refresh rate    
    }
}

/*
** ===================================================================
** processPerformanceMetrics()
** ===================================================================
*/
void processPerformanceMetrics()
{

    if (millis() > requestDueTime)
    {
        bool heapWarning = !(Monitor::watchHeap(HEAP_LOW_THRESHOLD));
        if (heapWarning)
        {
            // ui.setBackground(TFTColor::SC_LowHeap, true);   
            // char s[50];
            // snprintf(s, sizeof(s), "Low Heap: %u", Monitor::getFreeHeap());
            // ui.drawTextToLCD(s, (ui.getCenterHeight() - 10));
            // vTaskDelay(pdMS_TO_TICKS(3000)); // 3 second delay to keep msg up
        }
        Monitor::dumpStats(LOGTAG_METRICS);
        Monitor::logUptime(LOGTAG_METRICS);
        requestDueTime = millis() + delayBetweenRequests;

    } 

}

/*
** ===================================================================
** handleTouchInput()
** ===================================================================
*/
void handleTouchInput()
{
    static bool isTouchInProgress = false;
    int16_t rawX = 0;
    int16_t rawY = 0;
    if (touch.raw(rawX, rawY))
    {
        // track touch has started
        isTouchInProgress = true;

        // The CST8xx reports in the panel's native orientation and the panel is
        // square, so unlike the original board there is no portrait-to-
        // landscape flip to undo here.
        TS_Point p(rawX, rawY, 0);
        const uint16_t touchX = p.x;
        const uint16_t touchY = p.y;

        bIsInitialLift = false;
        if (!bIsInitialPress)
        {

            spLogI(LOGTAG_INPUT, "Initial Press Detected x=%d, y=%d", touchX, touchY);
            bIsInitialPress = true;

            UBaseType_t        messagesInQueue = uxQueueMessagesWaiting(scuiQueue);

            pActiveView->onTouchDown(p);

            // if there was a message in the queue when the press took place, 
            // there is a good chance that the UI is being updated and the onTouchDown()
            // event which happens immediately will act in the middle of something.  Leaving
            // this for now since responding immediately can be a good thing but let's 
            // at least clean up afterwards if something paints on top of the resulting
            // action.  TODO: Consider putting user input on the queue instead of letting it
            // interrupt whatever is going on; however, if this works reasonably well
            // it might be worth leaving as is since it provides a bit of responsiveness.
            if (messagesInQueue > 1)
            {
                spLogI(LOGTAG_GENERAL, "Pending messages in queue when processing touch. count: %u", messagesInQueue);
                SCUIMessage msg;
                msg.type = SCUIMessageType::UM_MARK_DIRTY;
                msg.str  = "";
                msg.num  = true;

                Monitor::start(MONITOR_ID_SCUI_QUEUE_DELAY, LOGTAG_MULTITASK, "handleTouchInput()");
                if (xQueueSend(scuiQueue, &msg, pdMS_TO_TICKS(10)) != pdPASS)
                {
                    spLogE(LOGTAG_PLAYER, "Failed to send SCUI message to queue");
                }                    
            }

        }
    } 
    else
    {
        if (isTouchInProgress)
        {
            bIsInitialPress = false;
            if (!bIsInitialLift)
            {
                bIsInitialLift    = true;
                isTouchInProgress = false;
                pActiveView->onTouchUp();
            } 
        }
    }    
}
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

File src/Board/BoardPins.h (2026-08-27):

/*-------------------------------------------------------------------------------------------------
**
** BoardPins.h
**
**    Hardware definition for the Elecrow CrowPanel 2.1" HMI ESP32 Rotary Display
**    (480x480 IPS round touch knob screen, ESP32-S3-N16R8).
**
**    Every value here is transcribed from Elecrow's own factory firmware
**    (factory_soucecode/ESP32_Display_2_1-1), which is the code that ships on the
**    unit. Two other vendor sources disagree and are deliberately NOT followed:
**
**      - example/Simple example/Encoder_code  claims A=45, B=42, SW=41
**      - the Elecrow wiki page                claims encoder B=44
**
**    Both contradict the factory firmware. Trust this file; it is the one that was
**    verified against the running board.
**
** SPDX-License-Identifier: MIT
** ------------------------------------------------------------------------------------------------
*/

#pragma once

#include <stddef.h>
#include <stdint.h>

// ---------------------------------------------------------------------------
// Panel geometry
// ---------------------------------------------------------------------------
static constexpr int16_t PANEL_WIDTH  = 480;
static constexpr int16_t PANEL_HEIGHT = 480;

static constexpr int16_t PANEL_CENTER_X = PANEL_WIDTH / 2;
static constexpr int16_t PANEL_CENTER_Y = PANEL_HEIGHT / 2;
static constexpr int16_t PANEL_RADIUS   = PANEL_WIDTH / 2;   // 240

// The addressable area is the full 480x480 square and the glass fills it — the
// round look comes from the board's bezel, not from a smaller active area. So
// layouts use the whole panel and are NOT inset. An earlier revision backed off
// to a 228px "safe radius" and simply wasted a visible ring of screen.
static constexpr int16_t PANEL_SAFE_RADIUS = PANEL_RADIUS;

// ---------------------------------------------------------------------------
// ST7701S RGB parallel bus
// ---------------------------------------------------------------------------
static constexpr int8_t LCD_CS    = 16;   // 3-wire SPI, init sequence only
static constexpr int8_t LCD_SCK   = 2;
static constexpr int8_t LCD_SDA   = 1;

static constexpr int8_t LCD_DE    = 40;
static constexpr int8_t LCD_VSYNC = 7;
static constexpr int8_t LCD_HSYNC = 15;
static constexpr int8_t LCD_PCLK  = 41;

static constexpr int8_t LCD_R0 = 46, LCD_R1 = 3,  LCD_R2 = 8,  LCD_R3 = 18, LCD_R4 = 17;
static constexpr int8_t LCD_G0 = 14, LCD_G1 = 13, LCD_G2 = 12, LCD_G3 = 11, LCD_G4 = 10, LCD_G5 = 9;
static constexpr int8_t LCD_B0 = 5,  LCD_B1 = 45, LCD_B2 = 48, LCD_B3 = 47, LCD_B4 = 21;

// Panel timing.
//
// SOURCE OF TRUTH: example/Arduino/RotaryScreen_2_1/RotaryScreen_2_1.ino in
// Elecrow's repo for this exact board. That file uses the SAME modern
// Arduino_GFX API this firmware uses, against a bundled copy of Arduino_GFX
// that is byte-identical to the 1.6.7 we build against. It is a reference
// implementation on an identical stack, not merely prior art.
//
// Two earlier attempts, both wrong, recorded so they are not retried:
//
//   1. factory_soucecode/ESP32_Display_2_1-1 — the porches below are right,
//      but it drives an older API and says nothing about polarity, clock or
//      bounce buffers. Sheared image.
//   2. example/esphome/*.yaml — h 20/10/10, v 8/10/10, 18MHz, pclk inverted.
//      Also sheared. ESPHome's st7701s component derives its peripheral
//      config differently, so its numbers do NOT transfer to Arduino_GFX.
//      Do not copy timings across driver stacks.
//
// The ST7701 fails soft: wrong values tear or shear the picture and never
// report an error. Do not tune these by feel.
static constexpr uint16_t LCD_HSYNC_FRONT_PORCH = 10;
static constexpr uint16_t LCD_HSYNC_PULSE_WIDTH = 4;
static constexpr uint16_t LCD_HSYNC_BACK_PORCH  = 20;
static constexpr uint16_t LCD_VSYNC_FRONT_PORCH = 10;
static constexpr uint16_t LCD_VSYNC_PULSE_WIDTH = 4;
static constexpr uint16_t LCD_VSYNC_BACK_PORCH  = 20;

// Sync polarity. Arduino_GFX INVERTS this on the way to ESP-IDF:
// Arduino_ESP32RGBPanel.cpp sets `hsync_idle_low = (hsync_polarity == 0)`.
// Passing 0 therefore makes sync idle LOW, which no working configuration for
// this panel does. The reference passes 1.
static constexpr uint16_t LCD_HSYNC_POLARITY = 1;
static constexpr uint16_t LCD_VSYNC_POLARITY = 1;

// Pixel clock: 12 MHz on the rising edge.
static constexpr int32_t  LCD_PCLK_HZ         = 12000000;
static constexpr uint16_t LCD_PCLK_ACTIVE_NEG = 0;

// DMA bounce buffers — two, 20 lines each.
//
// With 0 (the library default) the LCD GDMA fetches every pixel straight from
// PSRAM. The Arduino build here has CONFIG_LCD_RGB_RESTART_IN_VSYNC=y, so a
// missed DMA deadline makes the scanline pointer slip and then re-zero at each
// VSYNC — which renders as a STABLE diagonal shear rather than random flicker.
// That is exactly the artefact this board showed.
static constexpr size_t LCD_BOUNCE_BUFFER_PX = PANEL_WIDTH * 20;
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

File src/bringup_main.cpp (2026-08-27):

/*-------------------------------------------------------------------------------------------------
**
** bringup_main.cpp
**
**    Phase 1 entry point: proves the CrowPanel 2.1" hardware before any of the
**    Spotify application is ported onto it.
**
**    Every line it prints is an acceptance gate in GATES.md. The markers are
**    matched literally by `hwlog wait`, so do not reword them without editing
**    the ledger to match.
**
**    Built only when BRINGUP is defined; the real application owns main.cpp.
**
** SPDX-License-Identifier: MIT
** ------------------------------------------------------------------------------------------------
*/

#ifdef BRINGUP

#include <Arduino.h>
#include <Wire.h>

#include "Board/BoardPins.h"
#include "Board/Expander.h"
#include "Board/Knob.h"
#include "Board/RoundDisplay.h"
#include "Board/Touch.h"

static void scanI2C() {
  int found = 0;
  for (uint8_t addr = 1; addr < 127; addr++) {
    Wire.beginTransmission(addr);
    if (Wire.endTransmission() == 0) {
      Serial.printf("I2C device at 0x%02X\n", addr);
      found++;
    }
  }
  Serial.printf("I2C scan complete, %d device(s)\n", found);
}

void setup() {
  Serial.begin(115200);

  // Native USB-Serial/JTAG drops everything written before the host opens the
  // port, so the boot marker would be lost on a cold start without this wait.
  const uint32_t waitUntil = millis() + 2500;
  while (!Serial && millis() < waitUntil) {
    delay(10);
  }
  delay(200);

  Serial.println();
  Serial.println("SPOTIFY-KNOB boot");
  Serial.printf("build %s %s\n", __DATE__, __TIME__);
  Serial.printf("PSRAM %u bytes, free heap %u\n",
                (unsigned)ESP.getPsramSize(), (unsigned)ESP.getFreeHeap());

  if (ESP.getPsramSize() == 0) {
    Serial.println("FATAL: no PSRAM — the 460KB framebuffer cannot be allocated");
  }

  Wire.begin(I2C_SDA_PIN, I2C_SCL_PIN, I2C_FREQ_HZ);
  scanI2C();

  // P2 (touch INT) and P5 (encoder SW) are read back, so they must be held high.
  const uint8_t inputMask = (uint8_t)((1u << PCF_TOUCH_INT) | (1u << PCF_ENCODER_SW));
  if (expander.begin(inputMask)) {
    Serial.printf("EXPANDER ok 0x%02X\n", PCF8574_ADDR);
  } else {
    Serial.println("EXPANDER FAIL");
  }

  if (display.begin()) {
    display.drawTestPattern();
    Serial.printf("PANEL ok %dx%d\n", PANEL_WIDTH, PANEL_HEIGHT);
  } else {
    Serial.println("PANEL FAIL");
  }

  if (touch.begin()) {
    Serial.printf("TOUCH ok 0x%02X\n", TOUCH_I2C_ADDR);
  } else {
    Serial.println("TOUCH FAIL");
  }

  if (knob.begin()) {
    Serial.printf("KNOB ok A=%d B=%d SW=PCF.P%d\n",
                  ENCODER_A_PIN, ENCODER_B_PIN, PCF_ENCODER_SW);
  } else {
    Serial.println("KNOB FAIL");
  }

  Serial.println("bring-up ready — turn the knob, press it, touch the screen");
}

void loop() {
  KnobEvent ke;
  while (knob.poll(ke)) {
    switch (ke.type) {
      case KnobEventType::Rotate:
        // Clockwise must report dir=+1. If it reports -1, A and B are swapped
        // relative to BoardPins.h and the ledger's G6 has caught it.
        Serial.printf("KNOB dir=%+d delta=%d pos=%ld\n",
                      (ke.delta > 0) ? 1 : -1, (int)ke.delta, (long)knob.position());
        break;
      case KnobEventType::Press:
        Serial.println("KNOB press");
        break;
      case KnobEventType::LongPress:
        Serial.println("KNOB longpress");
        break;
      default:
        break;
    }
  }

  TouchEvent te;
  if (touch.poll(te)) {
    const char *name = "?";
    switch (te.gesture) {
      case TouchGesture::Tap:        name = "tap";    break;
      case TouchGesture::SwipeLeft:  name = "left";   break;
      case TouchGesture::SwipeRight: name = "right";  break;
      case TouchGesture::SwipeUp:    name = "up";     break;
      case TouchGesture::SwipeDown:  name = "down";   break;
      default: break;
    }
    Serial.printf("TOUCH x=%d y=%d gesture=%s\n", te.x, te.y, name);
  }

  delay(5);
}

#endif  // BRINGUP

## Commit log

2026-08-27 Initial import
    [custom_no_ota.csv]
2026-08-27 Add CrowPanel 2.1" rotary display board layer and Phase 1 bring-up
    Ports the target hardware layer for the Elecrow CrowPanel 2.1" ESP32-S3
    rotary display (480x480 round ST7701S RGB panel, CST8xx touch, encoder).
    The upstream ThingPulse target drives an SPI ILI9488 through TFT_eSPI,
    which cannot address an RGB parallel panel, so the display and input
    layers are replaced rather than reconfigured.
    - BoardPins.h: pinout transcribed from Elecrow's factory firmware. Two
    other vendor sources disagree and are documented as rejected.
    - Expander: PCF8574 at 0x21 carries LCD power, LCD reset, touch reset
    and the encoder switch, so the panel cannot come up over GPIO alone.
    - RoundDisplay: ST7701S b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
    [crowpanel_16mb.csv]
2026-08-27 Port the application layer to Arduino_GFX; add knob volume and resume
    Reuses the whole ThingPulse Spotify stack unchanged by shimming the
    drawing surface rather than rewriting it. DisplayUI.cpp (60KB) and the
    UIViews renderers now compile against the RGB parallel panel with no
    edits to either.
    - TFTCompat: TFT_eSPI-shaped facade over Arduino_GFX. Covers only the
    15 methods the application actually calls, so an unported call fails
    at build time instead of silently drawing nothing. include/TFT_eSPI.h
    redirects the original include; the real library is not a dependency
    and cannot drive an RGB parallel panel.
    - SpotifyPlayer: adds togglePlayPause(), nudgeVolume(),
    commitPendingVolume(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
    [BoardPins.h, RoundDisplay.cpp, TFTCompat.h]
2026-08-27 Fix sheared panel, static-init crash, and the rejected OAuth redirect
    Three defects found on hardware, each with a root cause worth recording.
    1. Sheared display. Every panel timing value taken from Elecrow's Arduino
    factory sketch is wrong, giving diagonal tearing rather than an image.
    Elecrow's own ESPHome config for the same board has the working
    values: h 20/10/10, v 8/10/10, 18MHz pixel clock, inverted. The
    sketch even contradicted its own literals in its comments
    (`4 /* hsync_pulse_width(8) */`). The ST7701 fails soft here — bad
    porches tear the picture instead of reporting an error.
    2. Null-callback crash on the first JPEG. DisplayUI's constructor called
    TJpgD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
    [BoardPins.h, RoundDisplay.cpp, TFTCompat.h]
2026-08-27 Fix album art TLS failure and invert knob direction
    Album art: add DigiCert Global Root G3 to the pinned CA bundle.
    The art CDN i.scdn.co is now served by "DigiCert Global G3 TLS ECC
    SHA384 2020 CA1", which chains to DigiCert Global Root G3. The bundle
    held only Global Root G2 and GlobalSign R3, so every art fetch failed
    TLS validation while metadata kept working — api.spotify.com still
    chains to G2, which is why the failure looked art-specific rather than
    like a certificate problem.
    The added root was checked against the live chain before committing:
    openssl s_client -connect i.scdn.co:443 -CAfile <root>
    -> Verify return code: 0 (ok)
    Knob: invert the quadrature se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
    [Knob.cpp]
2026-08-27 Fix the sheared panel: use Elecrow's Arduino_GFX reference config
    The panel now renders. Root cause was using the wrong vendor reference.
    Elecrow ships TWO Arduino examples and every previous attempt read the
    wrong one. example/Arduino/RotaryScreen_2_1/RotaryScreen_2_1.ino drives
    this exact board through the SAME modern Arduino_GFX API this firmware
    uses, and Elecrow bundles an Arduino_GFX copy beside it that is
    byte-identical to the 1.6.7 we build against. It is a reference
    implementation on an identical stack, not merely prior art.
    Five parameters were wrong:
    hsync/vsync polarity 0 -> 1
    porches h and v 20/10/10 -> 10/4/20
    8/10/10 -> 10/4/20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
    [BoardPins.h, RoundDisplay.cpp]
2026-08-27 Add circle-native RoundNowPlayingView; fix byte-swapped album art
    The ThingPulse HomeView is a 480x320 landscape layout: on the round
    480x480 panel the bezel clips text at every corner and the bottom third
    of the circle sits empty. RoundNowPlayingView replaces it in the Home
    slot with a design built for the circle:
    - 300x300 album art dead-center (half-diagonal 212 < 240, so the
    whole square is inside the visible circle)
    - the perimeter ring (r 226-238) IS the progress bar: Spotify green,
    sweeping clockwise from 12 o'clock, painted incrementally so it
    never flickers
    - clock and play-state glyph in the top band; title and artists in
    the bottom band, truncated to the cho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
    [TFTCompat.h, main.cpp]
2026-08-27 Add the enclosure fit-gauge ring
    First physical artefact of the shell track, per the claude-pet lesson:
    print the cheap gauge before the expensive shell (that project's v1
    case was modelled on unverified dimensions and printed >2mm off).
    One ring, three stacked bore steps over the board's 79.00mm body
    cylinder (dimension from Elecrow's own STEP file, corroborated by a
    caliper report; the listing's "5.3cm" is wrong):
    bottom 79.60 loose 1 rim notch
    middle 79.35 target 2 rim notches
    top 79.15 snug 3 rim notches
    Push the board in from the wide end; the step it seats at is the bore
    the cradle gets. Lead-in chamfer on the mouth, notch counts identify
    the steps off the print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
    [gauge_ring.stl, spotify_knob_gauge.FCStd]
2026-08-27 Ledger: record evidence for G10, G11, G13, G16 control, G17; add G18/G19
    G16's positive control is met by a genuine crash rather than a
    deliberate panic build: the TJpgDec null-callback reboot loop was
    reported by hwlog crashes with a full register dump, proving the
    detector works, so its silence during the soak now carries weight.
    G13's note records why the log marker alone was insufficient — the
    marker also printed with (FAILED) when no device was active, so the
    user's audible confirmation is part of the evidence, not decoration.
    via [Happy](https://happy.engineering)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
2026-08-27 Redesign the round view: art-first, no ring, on-art text, quiet chrome
    Owner feedback drove three cuts in sequence: volume must not cover the
    ring, then the whole progress ring goes, then general "looks ugly".
    The design that ships:
    - album art dead-center; title and artists ON the art over a true 50%
    scrim (framebuffer read-modify-write, (p>>1)&0x7BEF per pixel)
    - small dim clock at the top; no play triangle, no status box, no
    download box — dev chrome suppressed on this view
    - volume appears only while the knob turns: number + slim bar in the
    black zone under the art, self-dismissing with one rect
    - pause dims the whole art with centered bars; resume repaints
    Root c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
    [RoundDisplay.cpp, TFTCompat.h]
2026-08-27 Subscribe the song-refresh task to the task watchdog
    ESP32 Arduino core 3.x no longer auto-subscribes tasks, so the
    esp_task_wdt_reset() in refreshCurrentSongTask logged
    E task_wdt: esp_task_wdt_reset(707): task not found
    on every loop — thousands of pure-noise error lines per hour, ~2% of
    all log traffic in the soak measurement. One esp_task_wdt_add(NULL) at
    task start fixes it; if the WDT is not initialized the call fails
    harmlessly and behavior is unchanged.
    Built, not yet flashed: a 12-minute crash soak is running on the board
    against the previous commit and flashing would reset it. Flash together
    with whatever the owner's design verdict brings.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
2026-08-27 Add the tilted desk base, v1 (STEP-derived dims, caliper-pending)
    Nest-thermostat posture at the owner's chosen 35-degree recline. The
    knob's fixed lower band drops into a 9mm pocket sunk into the sloped
    face (deliberately shallower than the 12.5mm band so the cradle lip can
    never rub the rotating knob), the rear boss stack passes into a tunnel
    that exits the back as an open arch, and the USB cable leaves through a
    doorway under it. Prints flat-bottom-down; only the pocket interior
    wants slicer supports.
    Construction lesson recorded in the script: build one wedge from a box
    minus a half-space whose plane IS the face, then cut every cavity as a
    cylinder along the single tilted axis vector. T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
    [base_v1.stl, spotify_knob_base.FCStd]
2026-08-27 Ledger: close G4-G18 on owner confirmation and the 12-minute soak
    The soak ran on the shipped UI build with live owner interaction inside
    the window - a stronger test than an idle soak. G4 is abandoned as
    superseded rather than silently checked: the full application rendering
    live data is strictly stronger evidence than the bring-up pattern it
    asked for. Only G19 (gauge/base print fit) remains open, and it awaits
    plastic, not code.
    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
2026-08-27 Base: fold in the owner's caliper measurements
    Band height 12.5 confirmed exactly (pocket depth 9 now rests on a
    measured number, not a STEP guess). Boss OD 47.87 (STEP 48.00). Cable
    slot narrowed 15 -> 12 around the measured 9.03 plug.
    Two judgment calls recorded in the script:
    - The owner's first reading (47.87) was interpreted as the rear boss,
    not the front disc: the disc cannot physically be 47.87 (the 2.1"
    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
    [base_v1.stl, spotify_knob_base.FCStd]
2026-08-27 Panel: force a true cold-start; drop the task-watchdog subscription
    The PCF8574 keeps LCD power latched through a warm reboot, so after a
    crash storm the ST7701 could wedge dark while the firmware ran fine.
    Cutting the rail for 150ms makes every boot equivalent to first plug-in.
    The song-refresh task blocks on TLS and art downloads longer than the
    watchdog window, so subscribing it armed a panic around slow-but-alive
    I/O. No subscription, no reset — the honest form of what always was.
    via [Happy](https://happy.engineering)
    [RoundDisplay.cpp]
2026-08-27 Rebrand as spotKnob: strip upstream badging, redesign the README
    Rename src/ThingPulse/ to src/Core/, delete the dead other-board code
    (FT6236 driver, display.h, the reference-only build env, the boot
    logo), and reword narrative comments. The MIT LICENSE and per-file
    SPDX copyright notices stay — attribution is legal record, not badging.
    README rebuilt banner-first; the banner image itself lands separately.
    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
2026-08-27 Ledger: close G20-G22 and G24-G26 on direct evidence; G23 awaits the banner
    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
2026-09-24 Vendor spotify-api-arduino at 6261278, unchanged
    The library was fetched from GitHub at a pinned commit. It hard-defines
    SPOTIFY_DEBUG in its header, so no build flag can turn that off, and in
    that mode refreshAccessToken() prints the whole token request body -
    refresh token and client secret - to serial on every refresh.
    This commit copies the pinned sources into lib/SpotifyArduino as they
    are, so the fix that follows is a readable diff against upstream.
2026-09-24 Trust accounts.spotify.com's new root, and stop printing secrets to serial
    Every access-token refresh failed with
    "(-9984) X509 - Certificate verification failed", so the knob sat on
    "Waiting for music" while the API itself was fine. accounts.spotify.com
    now chains leaf -> Certainly Intermediate R1 -> Starfield Root
    Certificate Authority - G2. The shared TLS client trusted only the
    library's DigiCert Global Root G2, which still covers api.spotify.com.
    - src/Core/spotify.h: a spotify_api_root_certs bundle of DigiCert G2 and
    Starfield Root G2 (SHA256 2C:E1:CB:0B..., valid to 2037-12-31). The
    shared client now uses it. Checked with OpenSSL 3 and the system store
    switched off: G2 alone fa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
2026-09-24 Device picker: choose where the music plays, from the knob
    Hold the knob for 1.5 s from any screen to open a list of Spotify
    Connect devices (GET /v1/me/player/devices). Turn to move, press to
    play there (PUT /v1/me/player, device_ids + play:true). Hold, tap, or
    10 s of no input backs out with nothing changed. The existing 0.6 s
    hold (re-read volume) is unchanged and still fires first, on the way.
    - Knob: a VeryLongPress event at 1.5 s, once per hold, always after the
    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
2026-09-24 Knob: the long-press volume re-seed no longer blocks, so the 1.5 s hold opens the device picker
    The 0.6 s long press called refreshVolumeFromDevice() on the UI loop: it waited
    without a timeout for the network lock, then made a TLS request. The UI loop is
    the only reader of the knob switch, so the switch went unsampled for the whole
    call; a hold released before it returned never reached 1.5 s and the picker never
    opened. The long press now sets a flag that the background refresh task serves
    within ~100 ms.
    [main.cpp]
2026-09-24 Device picker: show the failure code on screen, and tell a bad reply (-2) from no connection (-1)
2026-09-24 Device picker: its Spotify calls run on the SongRefresh task, not the UI task
    The device GET from UIHandler connected and sent its request but read no status line
    within SPOTIFY_TIMEOUT (serial, 2026-09-23), while the same call returns 200 from
    SongRefresh and in 0.1 s from a Mac. The picker now posts a job to a one-slot queue that
    SongRefresh serves within ~100 ms, and collects the result on its idle tick. Also logs the
    DNS lookup, task and stack headroom at each fetch (diagnostic, to be removed).
2026-09-24 Stop printing encrypted credentials at boot, and drop the device-fetch diagnostic
    The vault printed the owner's Wi-Fi and Spotify secrets, encrypted with a key that ships
    in this source, on every boot. It now does so only when built with
    -DSPOTKNOB_PRINT_VAULT_HINTS (documented in the README). The DNS/stack diagnostic added
    while finding the picker bug is removed: the picker works from the SongRefresh task.
    [Vault.cpp]
